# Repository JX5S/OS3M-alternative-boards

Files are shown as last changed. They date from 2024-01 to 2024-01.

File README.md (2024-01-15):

# OS3M-alternative-boards
Boards based on the OS3M project, using 0603s and other components I like. I tried to get as few KiCAD warning as possible.

I haven't tested the boards and I'm planning to change them further before ordering, this repository is just for reference.

<p float="left">
  
   
</p>

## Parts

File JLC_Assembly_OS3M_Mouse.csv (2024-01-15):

Item | Qty | Reference(s) | Value | LibPart | Footprint | Datasheet | DNP | LCSC
1 | 2 | C1, C3 | 10u | Device:C | Capacitor_SMD:C_0603_1608Metric | ~ |  | C19702
2 | 2 | C2, C6 | 100n | Device:C | Capacitor_SMD:C_0603_1608Metric | ~ |  | C14663
3 | 5 | C4, C5, C7, C14, C15 | 1u | Device:C | Capacitor_SMD:C_0603_1608Metric | ~ |  | C15849
4 | 6 | C8, C9, C10, C11, C12, C13 | 1n | Device:C | Capacitor_SMD:C_0603_1608Metric | ~ |  | C1588
5 | 1 | D1 | BLUE_LED | Device:LED | LED_SMD:LED_0603_1608Metric | ~ |  | C72043
6 | 1 | J1 | USB_C_Receptacle_USB2.0 | Connector:USB_C_Receptacle_USB2.0 | Connector_USB:USB_C_Receptacle_G-Switch_GT-USB-7010ASV | https://www.usb.org/sites/default/files/documents/usb_type-c.zip |  | C2988369
7 | 1 | J2 | EXP_HDR | Connector:Conn_01x04_Female | Connector_PinSocket_2.54mm:PinSocket_2x02_P2.54mm_Horizontal | ~
8 | 1 | J3 | DBG_HDR | Connector:Conn_01x04_Socket | Connector_PinHeader_2.54mm:PinHeader_1x04_P2.54mm_Vertical | ~
9 | 1 | JP1 | SolderJumper_2_Open | Jumper:SolderJumper_2_Open | Jumper:SolderJumper-2_P1.3mm_Open_RoundedPad1.0x1.5mm | ~
10 | 1 | L1 | PCB_COIL | :PCB_COIL_1 | PCB_Coil:COIL_GENERATOR_0
11 | 1 | L2 | PCB_COIL | :PCB_COIL_3 | PCB_Coil:COIL_GENERATOR_0
12 | 1 | L3 | PCB_COIL | :PCB_COIL_4 | PCB_Coil:COIL_GENERATOR_0
13 | 1 | L4 | PCB_COIL | :PCB_COIL_2 | PCB_Coil:COIL_GENERATOR_0
14 | 1 | L5 | PCB_COIL | :PCB_COIL_5 | PCB_Coil:COIL_GENERATOR_0
15 | 1 | L6 | PCB_COIL | Coil_Library:PCB_COIL | PCB_Coil:COIL_GENERATOR_0
16 | 1 | R1 | 1M | Device:R | Resistor_SMD:R_0603_1608Metric | ~ |  | C22935
17 | 7 | R2, R3, R4, R5, R7, R8, R9 | 5k1 | Device:R | Resistor_SMD:R_0603_1608Metric | ~ |  | C23186
18 | 1 | R6 | 200 | Device:R | Resistor_SMD:R_0603_1608Metric | ~ |  | C8218
19 | 1 | SW1 | ~{RST} | Switch:SW_Push | Button_Switch_SMD:SW_Push_1P1T_XKB_TS-1187A | ~ |  | C318884
20 | 6 | TP1, TP2, TP3, TP4, TP5, TP6 | TestPoint | Connector:TestPoint | TestPoint:TestPoint_Pad_D2.0mm | ~
21 | 1 | U1 | AP2112K-3.3 | Regulator_Linear:AP2112K-3.3 | Package_TO_SOT_SMD:SOT-23-5 | https://www.diodes.com/assets/Datasheets/AP2112.pdf |  | C51118
22 | 1 | U2 | USBLC6-2SC6 | Power_Protection:USBLC6-2SC6 | Package_TO_SOT_SMD:SOT-23-6 | https://www.st.com/resource/en/datasheet/usblc6-2.pdf |  | C2827654
23 | 1 | U3 | STM32F042F6P6 | MCU_ST_STM32F0:STM32F042F6Px | Package_SO:TSSOP-20_4.4x6.5mm_P0.65mm | http://www.st.com/st-web-ui/static/active/en/resource/technical/document/datasheet/DM00105814.pdf |  | C2969989
24 | 1 | U4 | LDC1614 | Sensor_Proximity:LDC1614 | Package_DFN_QFN:WQFN-16-1EP_4x4mm_P0.5mm_EP2.6x2.6mm_ThermalVias | http://www.ti.com/lit/ds/symlink/ldc1612.pdf |  | C968448
25 | 1 | U5 | LDC1612 | Sensor_Proximity:LDC1612 | Package_SON:WSON-12-1EP_4x4mm_P0.5mm_EP2.6x3mm_ThermalVias | http://www.ti.com/lit/ds/symlink/ldc1612.pdf |  | C202191
26 | 1 | X1 | 40.000MHz | Oscillator:ASV-xxxMHz | Crystal:Crystal_SMD_3225-4Pin_3.2x2.5mm | http://www.abracon.com/Oscillators/ASV.pdf |  | C18203114

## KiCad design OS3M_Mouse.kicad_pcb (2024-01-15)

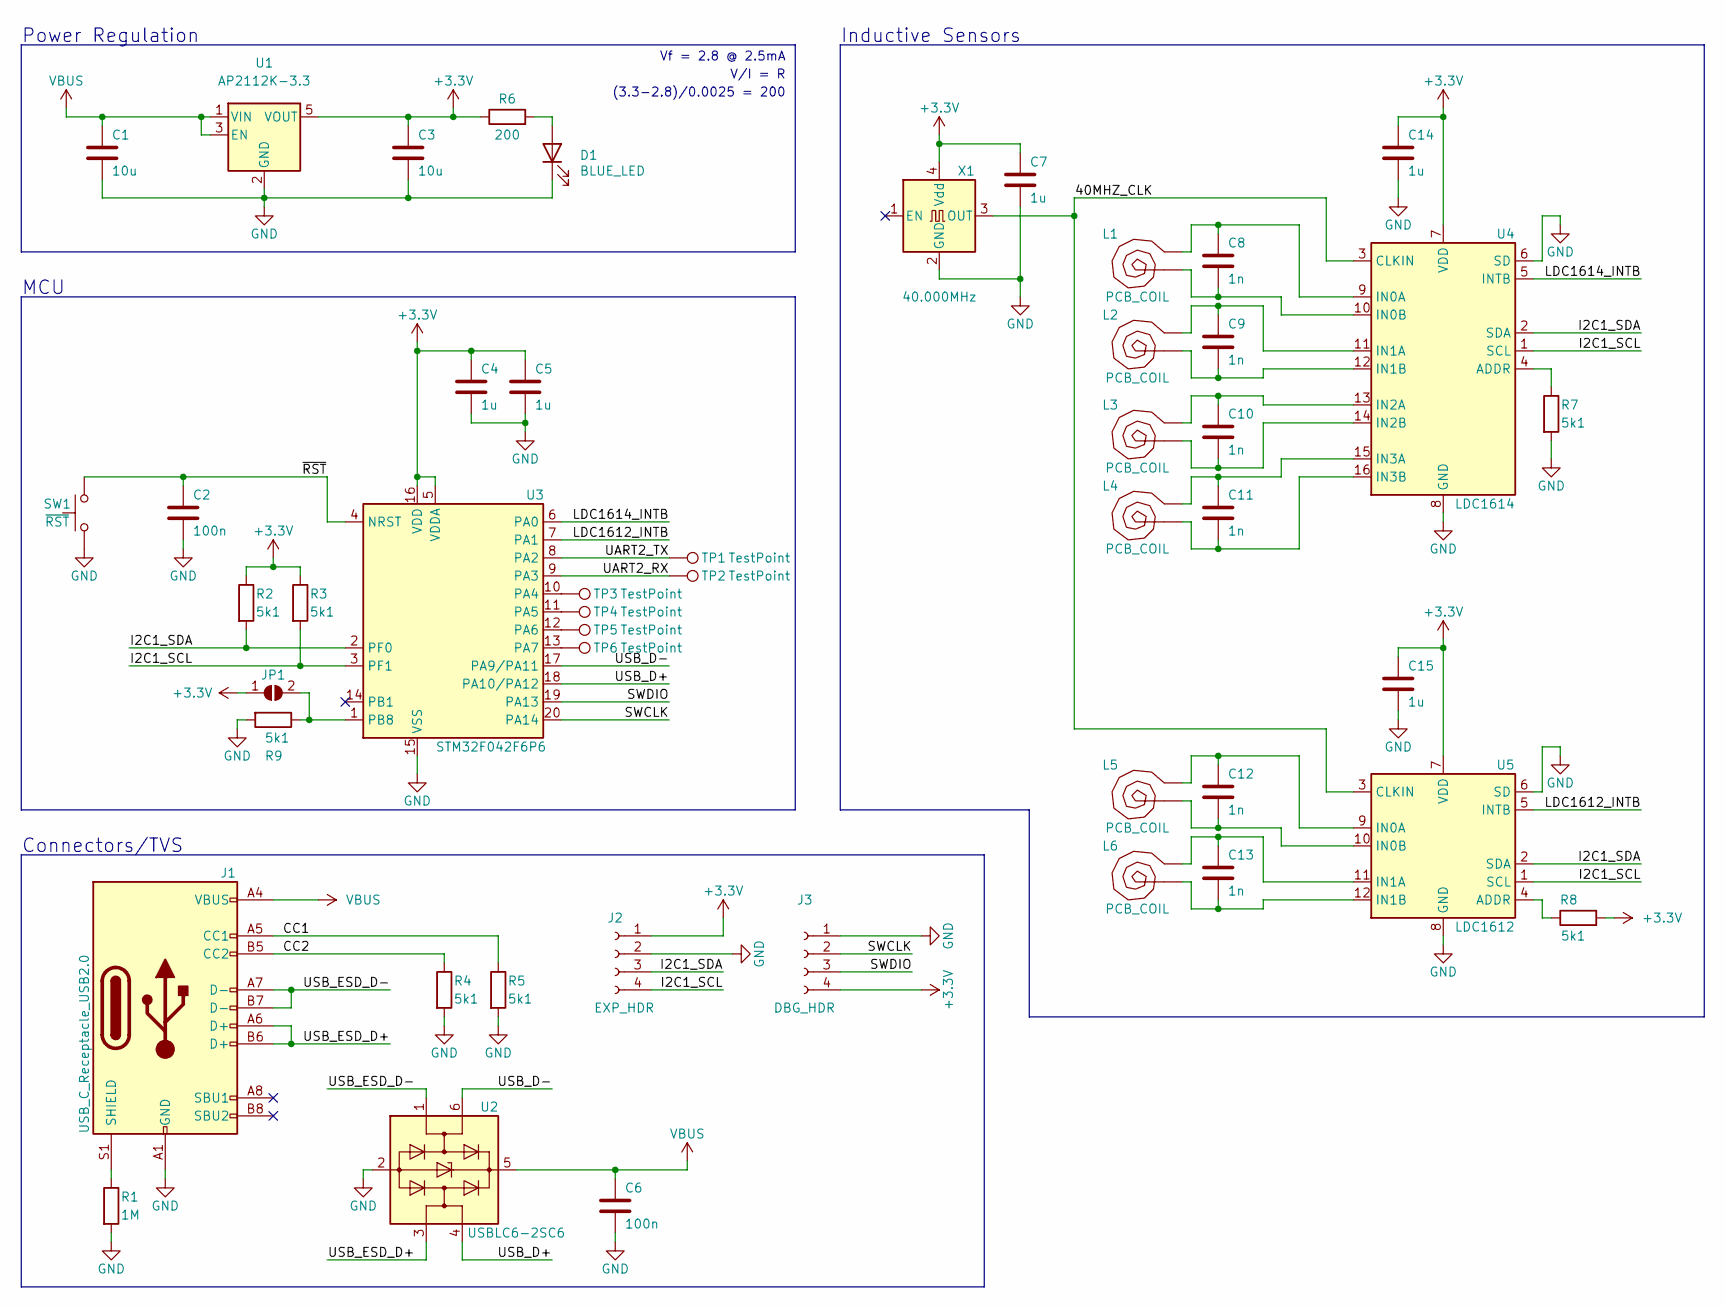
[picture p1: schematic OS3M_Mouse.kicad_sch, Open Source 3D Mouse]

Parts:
C1, C3: 10u; C_0603_1608Metric; LCSC C19702
C2, C6: 100n; C_0603_1608Metric; LCSC C14663
C4, C5, C7, C14, C15: 1u; C_0603_1608Metric; LCSC C15849
C8, C9, C10, C11, C12, C13: 1n; C_0603_1608Metric; LCSC C1588
D1: BLUE_LED; LED_0603_1608Metric; LCSC C72043
J1: USB_C_Receptacle_USB2.0; USB_C_Receptacle_G-Switch_GT-USB-7010ASV; LCSC C2988369
J2: EXP_HDR; PinSocket_2x02_P2.54mm_Horizontal
J3: DBG_HDR; PinHeader_1x04_P2.54mm_Vertical
JP1: SolderJumper_2_Open; SolderJumper-2_P1.3mm_Open_RoundedPad1.0x1.5mm
L1, L2, L3, L4, L5, L6: PCB_COIL; COIL_GENERATOR_0
R1: 1M; R_0603_1608Metric; LCSC C22935
R2, R3, R4, R5, R7, R8, R9: 5k1; R_0603_1608Metric; LCSC C23186
R6: 200; R_0603_1608Metric; LCSC C8218
SW1: ~{RST}; SW_Push_1P1T_XKB_TS-1187A; LCSC C318884
TP1, TP2, TP3, TP4, TP5, TP6: TestPoint; TestPoint_Pad_D2.0mm
U1: AP2112K-3.3; SOT-23-5; LCSC C51118
U2: USBLC6-2SC6; SOT-23-6; LCSC C2827654
U3: STM32F042F6P6; TSSOP-20_4.4x6.5mm_P0.65mm; LCSC C2969989
U4: LDC1614; WQFN-16-1EP_4x4mm_P0.5mm_EP2.6x2.6mm_ThermalVias; LCSC C968448
U5: LDC1612; WSON-12-1EP_4x4mm_P0.5mm_EP2.6x3mm_ThermalVias; LCSC C202191
X1: 40.000MHz; Crystal_SMD_3225-4Pin_3.2x2.5mm; LCSC C387435

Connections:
+3.3V: C3.1, C4.1, C5.1, C7.1, C14.1, C15.1, J2.1, J3.4, JP1.1 (A), R2.1, R3.1, R6.1, R8.2, U1.5 (VOUT), U3.5 (VDDA), U3.16 (VDD), U4.7 (VDD), U5.7 (VDD), X1.4 (Vdd)
/40MHZ_CLK: U4.3 (CLKIN), U5.3 (CLKIN), X1.3 (OUT)
/CC1: J1.A5 (CC1), R5.1
/CC2: J1.B5 (CC2), R4.1
/I2C1_SCL: J2.4, R3.2, U3.3 (PF1), U4.1 (SCL), U5.1 (SCL)
/I2C1_SDA: J2.3, R2.2, U3.2 (PF0), U4.2 (SDA), U5.2 (SDA)
/LDC1612_INTB: U3.7 (PA1), U5.5 (INTB)
/LDC1614_INTB: U3.6 (PA0), U4.5 (INTB)
/SWCLK: J3.2, U3.20 (PA14)
/SWDIO: J3.3, U3.19 (PA13)
/UART2_RX: TP2.1, U3.9 (PA3)
/UART2_TX: TP1.1, U3.8 (PA2)
/USB_D+: U2.4 (I/O2), U3.18 (PA10/PA12)
/USB_D-: U2.6 (I/O1), U3.17 (PA9/PA11)
/USB_ESD_D+: J1.A6 (D+), J1.B6 (D+), U2.3 (I/O2)
/USB_ESD_D-: J1.A7 (D-), J1.B7 (D-), U2.1 (I/O1)
/~RST: C2.1, SW1.2, U3.4 (NRST)
GND: C1.2, C2.2, C3.2, C4.2, C5.2, C6.2, C7.2, C14.2, C15.2, D1.1 (K), J1.A1 (GND), J1.A12 (GND), J1.B1 (GND), J1.B12 (GND), J2.2, J3.1, R1.2, R4.2, R5.2, R7.2, R9.2, SW1.1, U1.2 (GND), U2.2 (GND), U3.15 (VSS), U4.6 (SD), U4.8 (GND), U4.17 (GND), U5.6 (SD), U5.8 (GND), U5.13 (GND), X1.2 (GND)
unnamed: D1.2 (A), R6.2
unnamed: J1.S1 (SHIELD), R1.1
unnamed: JP1.2 (B), R9.1, U3.1 (PB8)
unnamed: TP3.1, U3.10 (PA4)
unnamed: TP4.1, U3.11 (PA5)
unnamed: TP5.1, U3.12 (PA6)
unnamed: TP6.1, U3.13 (PA7)
unnamed: R7.1, U4.4 (ADDR)
unnamed: C8.1, L1.1, U4.9 (IN0A)
unnamed: C8.2, L1.2, U4.10 (IN0B)
unnamed: C9.1, L2.1, U4.11 (IN1A)
unnamed: C9.2, L2.2, U4.12 (IN1B)
unnamed: C10.1, L3.1, U4.13 (IN2A)
unnamed: C10.2, L3.2, U4.14 (IN2B)
unnamed: C11.1, L4.1, U4.15 (IN3A)
unnamed: C11.2, L4.2, U4.16 (IN3B)
unnamed: R8.1, U5.4 (ADDR)
unnamed: C12.1, L5.1, U5.9 (IN0A)
unnamed: C12.2, L5.2, U5.10 (IN0B)
unnamed: C13.1, L6.1, U5.11 (IN1A)
unnamed: C13.2, L6.2, U5.12 (IN1B)
VBUS: C1.1, C6.1, J1.A4 (VBUS), J1.A9 (VBUS), J1.B4 (VBUS), J1.B9 (VBUS), U1.1 (VIN), U1.3 (EN), U2.5 (VBUS)

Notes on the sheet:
Inductive Sensors
MCU
Power Regulation
(3.3-2.8)/0.0025 = 200
V/I = R
Connectors/TVS
Vf = 2.8 @ 2.5mA

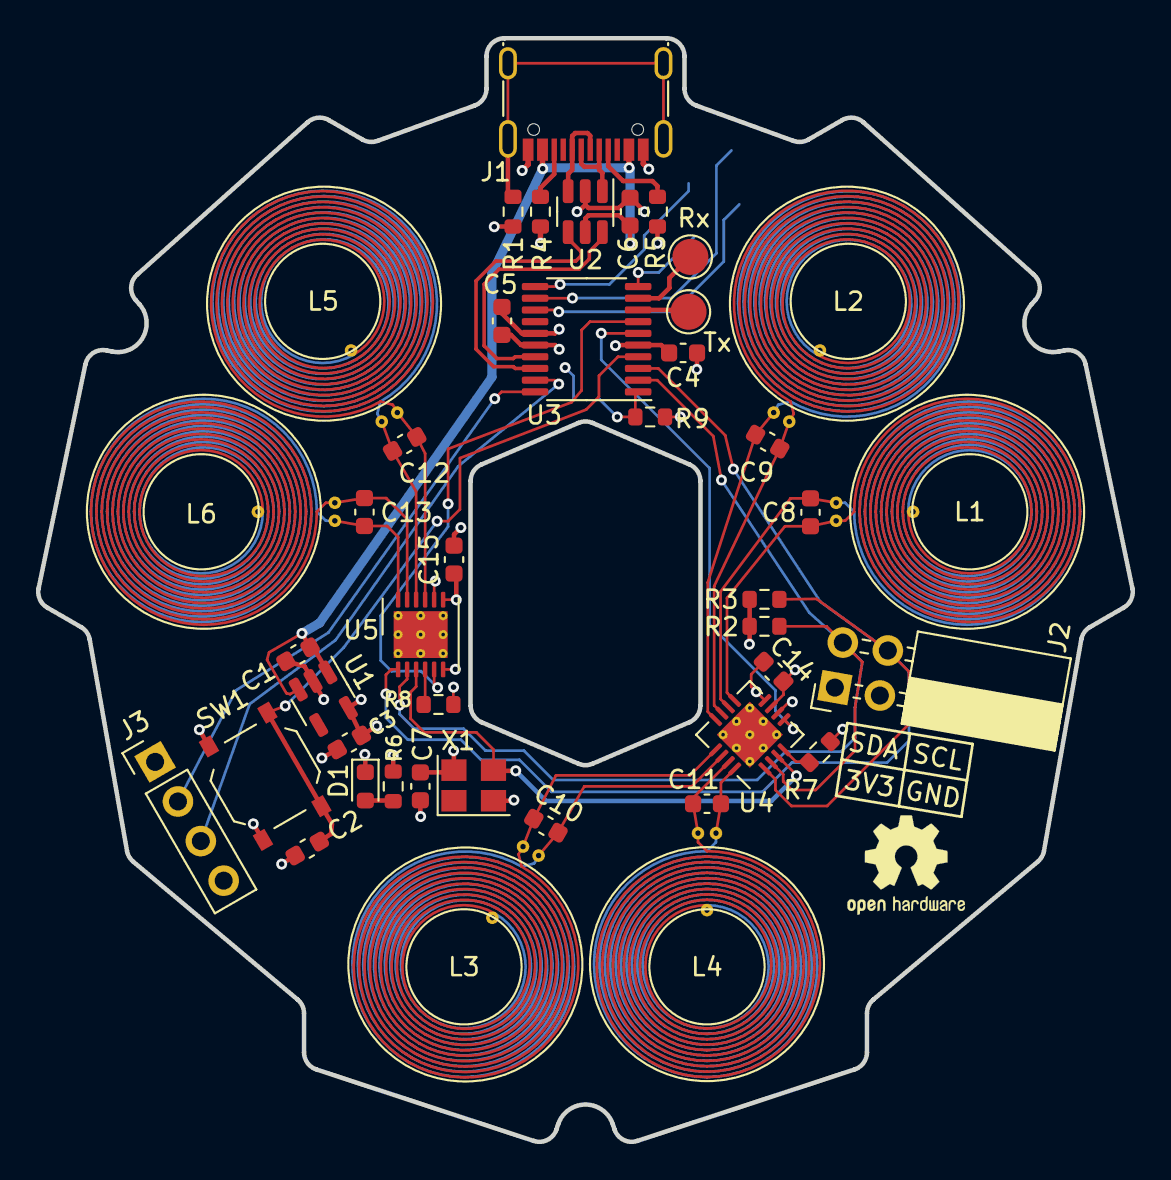
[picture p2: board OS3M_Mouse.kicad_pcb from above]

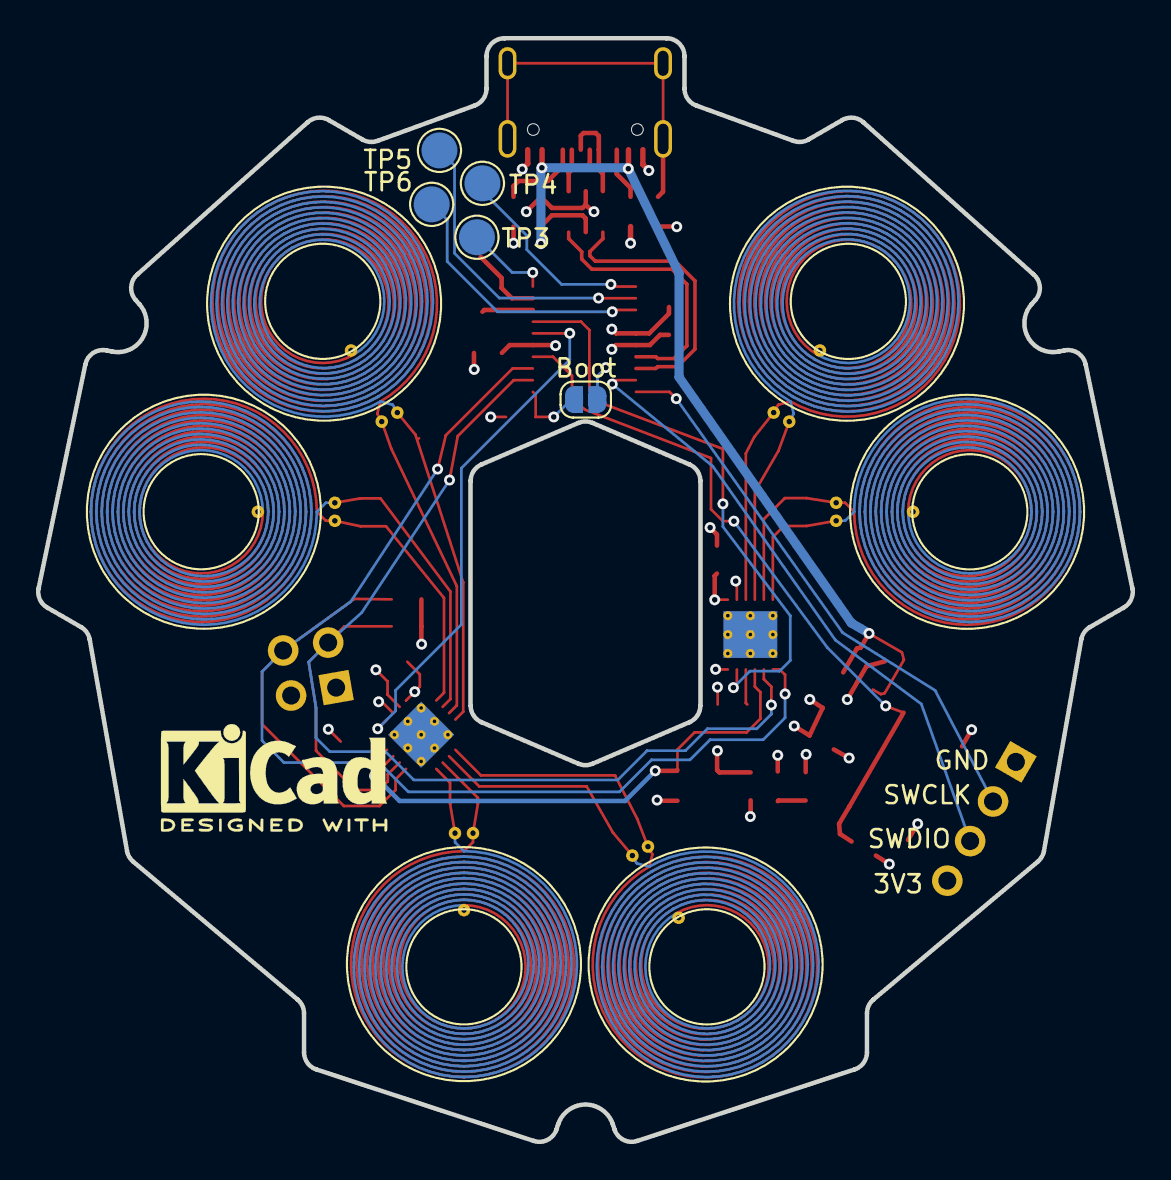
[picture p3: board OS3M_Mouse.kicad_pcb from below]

Board: 4 copper layers, 60.8 x 61.3 mm, 48 parts (5 on the bottom side), 40 nets.
